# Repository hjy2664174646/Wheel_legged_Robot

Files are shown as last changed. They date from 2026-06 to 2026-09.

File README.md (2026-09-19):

# Wheel_legged_Robot

双轮足式平衡机器人项目，包含 RK3576 上位机 ROS 2 工作空间和 STM32 控制板下位机固件。系统通过串口桥接上位机与下位机，可完成机器人状态发布、底盘速度控制、SLAM 建图和 Nav2 自主导航。

## 项目结构

```text
Wheel_legged_Robot/
├── fishbot_ws/              # RK3576 上位机 ROS 2 工作空间
│   └── src/
│       ├── fishbot_bringup/       # 机器人启动、串口桥、TF/URDF 启动
│       ├── fishbot_description/   # 基础机器人描述
│       ├── fishbot_navigation2/   # slam_toolbox 与 Nav2 配置、地图、launch
│       ├── lslidar_driver/        # 雷神雷达 ROS 2 驱动
│       ├── lslidar_msgs/          # 雷达消息定义
│       ├── ros_serial2wifi/       # 串口/WiFi 辅助通信节点
│       ├── wheel_legged_urdf_pkg/ # 双轮足机器人 URDF、网格和 RViz 配置
│       └── ydlidar_ros2/          # YDLidar ROS 2 驱动
├── wheel_legged_ros/        # STM32 控制板下位机工程
│   ├── Core/                # STM32CubeMX 生成的 HAL/FreeRTOS 基础代码
│   ├── Drivers/             # STM32 HAL、CMSIS 等驱动
│   ├── Middlewares/         # FreeRTOS 中间件
│   ├── User/                # 平衡控制、腿部/轮部控制、IMU、CAN、电机和 ROS 通信
│   └── MDK-ARM/             # Keil MDK 工程文件
├── solidworks/              # 机械结构、加工图纸和三维模型
│   ├── hhu外壳改版sw/       # 外壳改版零件及 STL/3MF 导出文件
│   ├── 机加工图纸及模型/    # DXF 图纸、STEP 模型和加工 BOM
│   └── 机械结构.zip         # 机械结构资料压缩包
└── install.txt              # 依赖安装和设备规则记录
```

## 功能

- 双轮足式平衡机器人底盘控制
- STM32 下位机读取 IMU、轮端状态并执行平衡/运动控制
- 上下位机串口通信，默认设备名为 `/dev/serial_ttl`
- 上位机发布机器人 TF、URDF、里程计和雷达数据
- 支持 `slam_toolbox` 在线建图
- 支持 Navigation2 载入地图并进行自主导航
- 支持 RViz 可视化调试
- 提供机器人外壳、零件和机加工相关的 CAD 资料

## 硬件与软件环境

### 上位机

- RK3576
- Ubuntu 22.04
- ROS 2 Humble
- 雷达设备，默认可配置为 `/dev/lidar`
- 与 STM32 控制板连接的串口，默认可配置为 `/dev/serial_ttl`

### 下位机

- STM32H723 控制板
- FreeRTOS
- STM32 HAL
- Keil MDK-ARM / STM32CubeMX
- BMI088 IMU
- 达妙 DM4310 电机及 CAN 通信链路

## 机械设计资料

`solidworks/` 目录保存轮足机器人的机械结构资料，主要包括：

- `hhu外壳改版sw/`: 外壳改版零件的 SolidWorks `SLDPRT` 源文件，以及用于加工、打印或快速查看的 `STL`、`3MF` 文件
- `机加工图纸及模型/`: 机加工零件的 `DXF` 图纸、`STEP` 三维模型和 `BOM` 表格
- `机械结构.zip`: 机械结构资料的打包备份

SolidWorks 临时锁文件（文件名以 `~$` 开头）不会提交到仓库。修改或重新导出 CAD 文件后，请同步检查对应的 URDF 网格和装配尺寸，避免机械结构与仿真模型不一致。
## 上位机依赖安装

```bash
sudo apt update

sudo apt install -y \
  ros-humble-navigation2 \
  ros-humble-nav2-bringup \
  ros-humble-slam-toolbox \
  ros-humble-rviz2 \
  ros-humble-robot-state-publisher \
  ros-humble-joint-state-publisher \
  ros-humble-joint-state-publisher-gui \
  ros-humble-tf-transformations \
  ros-humble-pcl-conversions \
  ros-humble-diagnostic-updater \
  ros-humble-xacro \
  python3-colcon-common-extensions \
  python3-rosdep \
  python3-serial \
  libpcap-dev \
  libpcl-dev
```

如果 `rosdep` 尚未初始化：

```bash
sudo rosdep init
rosdep update
```

将当前用户加入串口权限组，执行后需要重新登录：

```bash
sudo usermod -a -G dialout $USER
```

## 设备规则

建议为 STM32 串口和雷达配置固定设备名，避免 `/dev/ttyACM*`、`/dev/ttyUSB*` 编号变化。

创建规则文件：

```bash
sudo nano /etc/udev/rules.d/99-wheel-legged-robot.rules
```

写入以下内容，并根据实际 `idVendor` / `idProduct` 调整：

```bash
# STM32 控制板串口 -> /dev/serial_ttl
SUBSYSTEM=="tty", ATTRS{idVendor}=="2e88", ATTRS{idProduct}=="4603", MODE="0666", SYMLINK+="serial_ttl"

# 雷达串口 -> /dev/lidar
SUBSYSTEM=="tty", ATTRS{idVendor}=="1a86", ATTRS{idProduct}=="7523", MODE="0666", SYMLINK+="lidar"
```

加载规则：

```bash
sudo udevadm control --reload-rules
sudo udevadm trigger
```

重新插拔设备后检查：

```bash
ls -l /dev/serial_ttl
ls -l /dev/lidar
```

## 编译上位机 ROS 2 工作空间

```bash
source /opt/ros/humble/setup.bash
cd ~/fishbot_ws
rosdep install --from-paths src --ignore-src -r -y
colcon build
source install/setup.bash
```

如果项目目录不是 `~/fishbot_ws`，请替换为实际路径。

## 启动机器人

启动底层 bringup，包括 URDF/TF、串口桥和雷达驱动：

```bash
source /opt/ros/humble/setup.bash
source ~/fishbot_ws/install/setup.bash
ros2 launch fishbot_bringup bringup.launch.py
```

`fishbot_bringup` 默认串口参数：

- `serial_port`: `/dev/serial_ttl`
- `baudrate`: `115200`

## 建图

先启动机器人 bringup，再在另一个终端启动 SLAM：

```bash
source /opt/ros/humble/setup.bash
source ~/fishbot_ws/install/setup.bash
ros2 launch fishbot_navigation2 slam_toolbox.launch.py use_sim_time:=false
```

建图完成后可使用 `slam_toolbox` 或 Nav2 相关工具保存地图到 `fishbot_ws/src/fishbot_navigation2/maps/`。

## 导航

启动机器人 bringup 后，在另一个终端启动 Nav2：

```bash
source /opt/ros/humble/setup.bash
source ~/fishbot_ws/install/setup.bash
ros2 launch fishbot_navigation2 navigation2.launch.py \
  map:=$HOME/fishbot_ws/src/fishbot_navigation2/maps/room.yaml \
  use_sim_time:=false \
  params_file:=$HOME/fishbot_ws/src/fishbot_navigation2/config/nav2_params.yaml
```

启动后可在 RViz 中设置初始位姿，并通过 `Nav2 Goal` 下发导航目标点。

## 下位机固件

`wheel_legged_ros/` 为 STM32 控制板代码，主要包含：

- `User/Controller`: 平衡与底盘控制逻辑
- `User/APP`: 左右腿/轮任务、状态观测、IMU、ROS 通信任务
- `User/Devices`: BMI088、DM4310 等设备驱动
- `User/Algorithm`: PID、Kalman、EKF、Mahony、VMC 等算法
- `User/Bsp`: CAN、PWM、DWT 等板级支持

编译和烧录步骤：

1. 使用 Keil MDK-ARM 打开 `wheel_legged_ros/MDK-ARM/CtrlBoard-H7_IMU.uvprojx`
2. 检查 STM32H723 目标芯片、调试器和下载配置
3. 编译工程并通过 ST-Link/J-Link 下载到控制板
4. 确认控制板串口连接到 RK3576，并与上位机串口桥保持 115200 波特率

## 上下位机通信

上位机通过 `fishbot_bringup/src/serial_bridge_node.py` 与下位机串口通信。下位机 `User/APP/ros_common.c` 中实现速度指令解析和里程计/IMU 数据发送。

- 上位机向下位机下发线速度 `vx` 与角速度 `wz`
- 下位机回传速度、角速度、位姿、IMU 和姿态数据
- 数据帧使用 `0xAA 0x55` 作为帧头，并带校验字段

## 注意事项

- 默认 bringup 使用 `lslidar_driver` 中的 `lsn10_launch.py`，请根据实际雷达型号调整 launch 或参数文件
- 如果串口设备名不是 `/dev/serial_ttl`，请修改 `fishbot_bringup/launch/bringup.launch.py`
- 导航前需要确认 TF、里程计、雷达 `/scan` 数据正常
- 真实机器人调试前请先确认急停、电池、电机方向和限位保护
- CAD 资料包含二进制和较大的 DXF 文件，首次克隆或拉取更新可能需要较长时间
- 当前仓库保存的是零件、导出模型和加工资料；如需完整 SolidWorks 装配体，请同时保留对应的 `SLDASM` 和引用零件文件

## 许可证

本项目当前未声明开源许可证。如需公开发布和二次分发，建议补充合适的 LICENSE 文件。

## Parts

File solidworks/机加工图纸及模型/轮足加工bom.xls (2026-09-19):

物料名称 | 材料 | 数量 | 单价
LIANGAN1 | 6061铝合金 | 2
LIANGAN3 | 6061铝合金 | 2
LIANGAN2 | 6061铝合金 | 2
LIANGAN4 | 6061铝合金 | 2
LVGUAN-1 | 6061铝合金方管 | 4
LVGUAN-2 | 6061铝合金方管 | 2
LVGUAN-3 | 6061铝合金方管 | 1
BANJIEJIAN-1 | 玻纤板-FR4 | 4
BANJIEJIAN-2 | 玻纤板-FR4 | 2
DIBAN-1 | 玻纤板-FR4 | 1
LIANJIEBAN-1 | 玻纤板-FR4 | 2
DINGBAN | 玻纤板-FR4 | 1
DINGGAI | 玻纤板-FR4 | 1

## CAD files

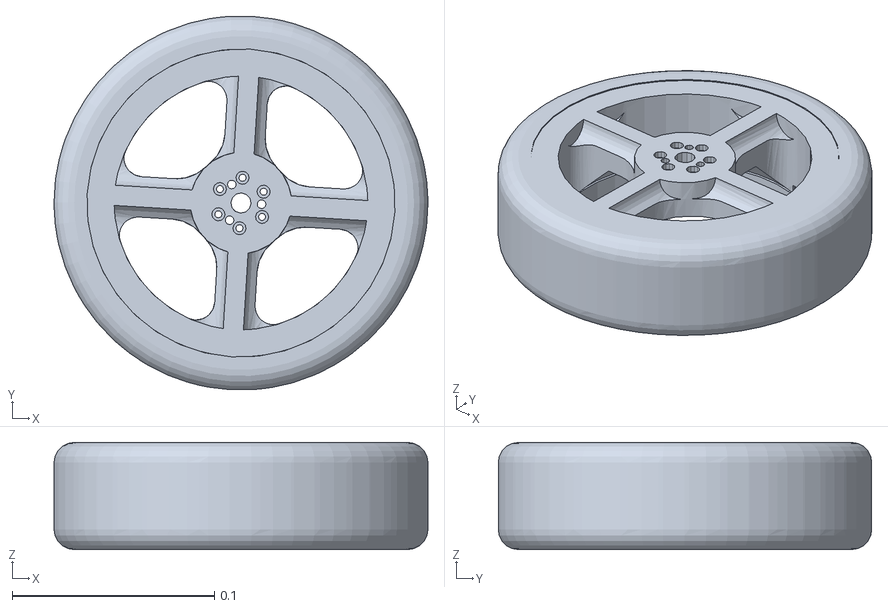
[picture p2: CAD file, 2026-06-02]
fishbot_ws/src/wheel_legged_urdf_pkg/meshes/right_wheel_motor_link.STL
0.185 x 0.185 x 0.053

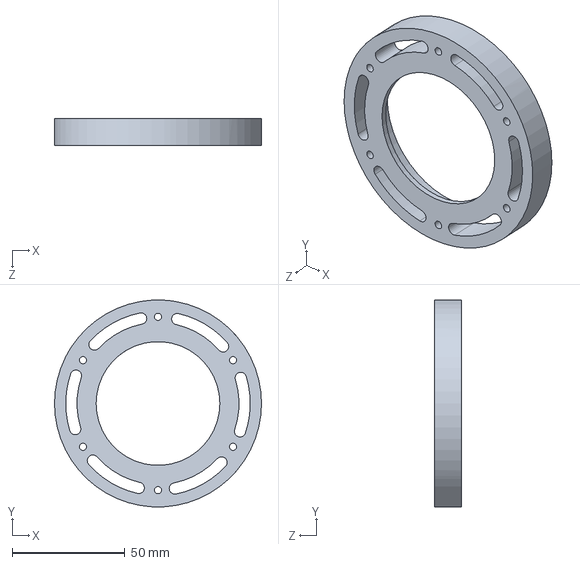
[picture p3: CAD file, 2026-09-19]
solidworks/hhu外壳改版sw/轮胎3.SLDPRT
92.0 x 91.8 x 12.0 mm

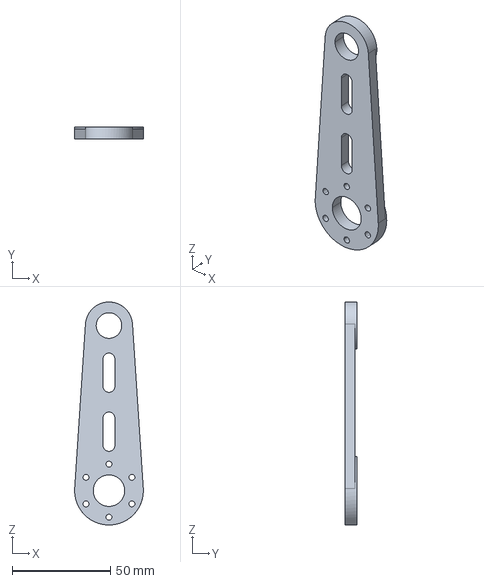
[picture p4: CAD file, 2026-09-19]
solidworks/机加工图纸及模型/liangan4.stp
35.0 x 6.00 x 113.5 mm

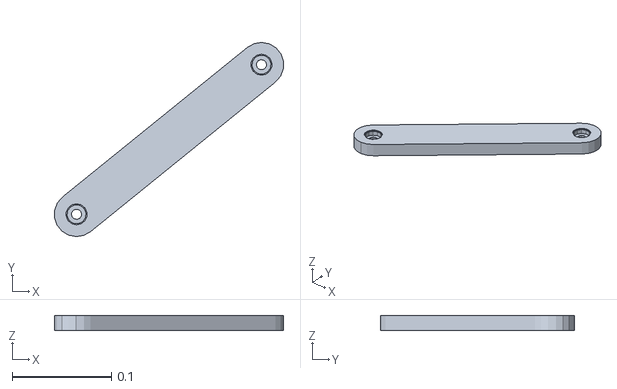
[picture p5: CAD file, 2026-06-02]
fishbot_ws/src/wheel_legged_urdf_pkg/meshes/right_l1_link.STL
0.231 x 0.196 x 0.015

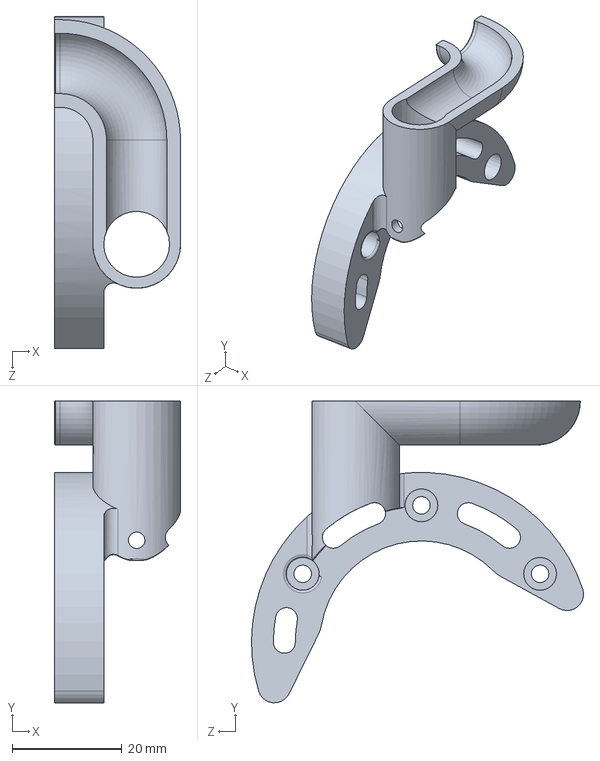
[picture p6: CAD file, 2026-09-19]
solidworks/hhu外壳改版sw/限位.SLDPRT
23.0 x 55.0 x 60.6 mm

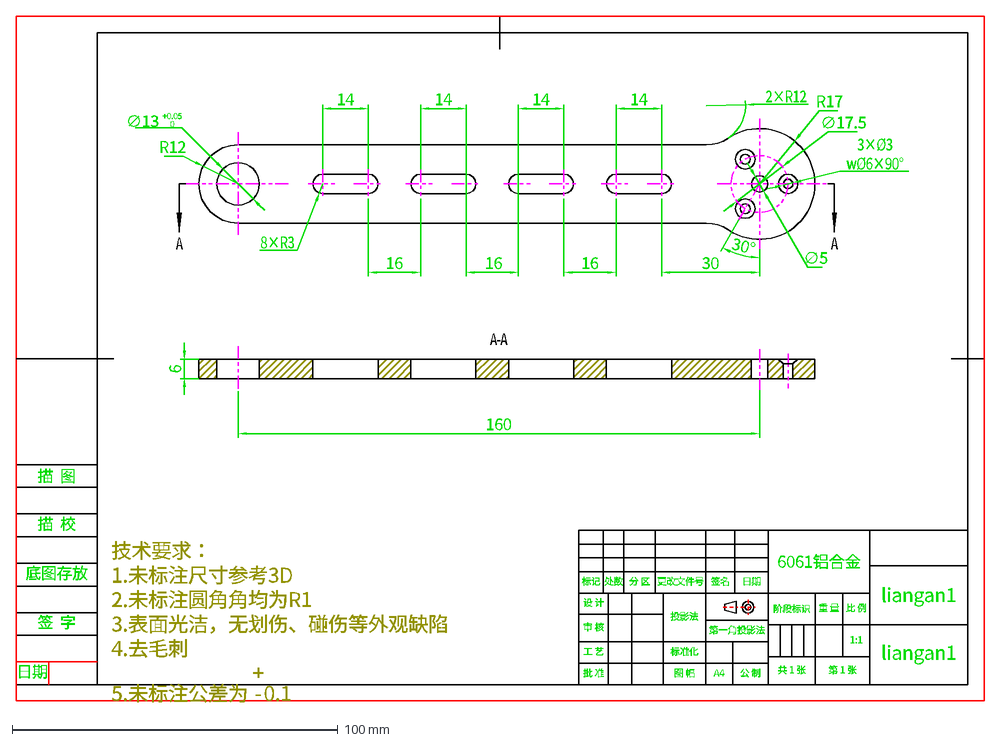
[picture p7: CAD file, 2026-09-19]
solidworks/机加工图纸及模型/liangna1.dxf
日期
签 字
底图存放
描 校
描 图
6061铝合金
liangan1
标记
处数
分 区
更改文件号
签名
设 计
投影法
阶段标识
重 量
比 例
审 核
第一角投影法
1:1
工 艺
标准化
共 1 张
第 1 张
批 准
图 幅
A4
公 制
技术要求： 1.未标注尺寸参考3D 2.未标注圆角角均为R1 3.表面光洁，无划伤、碰伤等外观缺陷 4.去毛刺 5.未标注公差为 +^-0.1
∅13 +0.05^0
R12
14
16
30
R17
6
160
30°
∅17.5
A-A
A
∅5

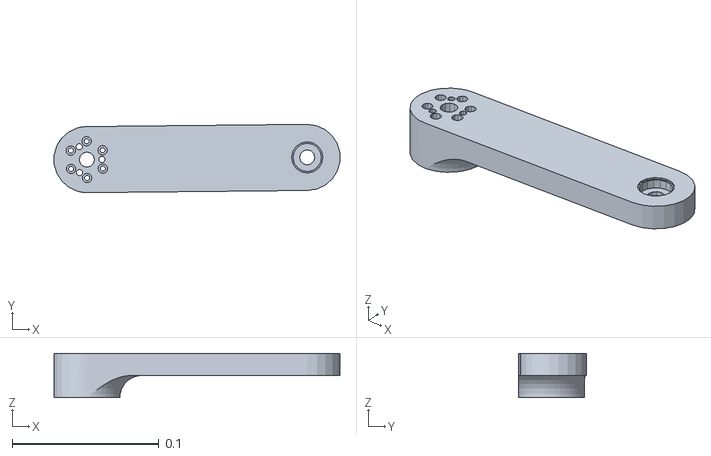
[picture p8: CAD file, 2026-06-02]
fishbot_ws/src/wheel_legged_urdf_pkg/meshes/left_front_motor_link.STL
0.195 x 0.0465 x 0.03

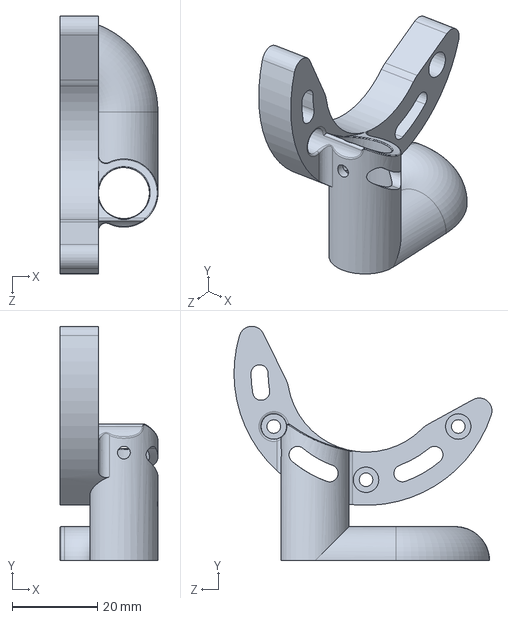
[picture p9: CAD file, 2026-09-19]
solidworks/hhu外壳改版sw/限位1.SLDPRT
23.0 x 55.0 x 60.6 mm

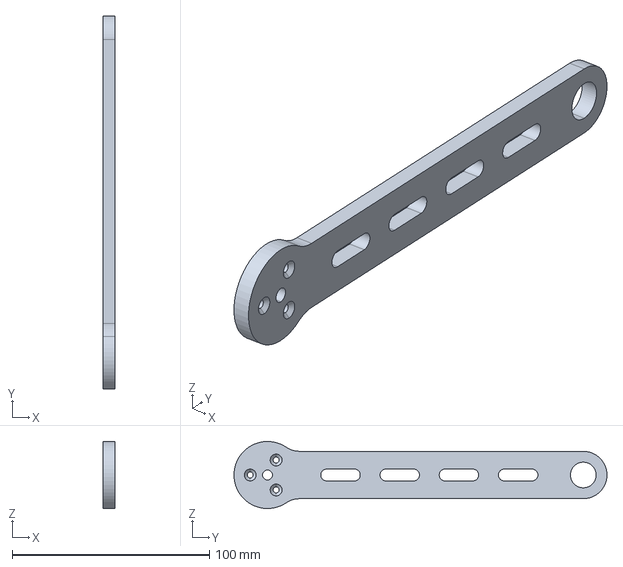
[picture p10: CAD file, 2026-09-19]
solidworks/机加工图纸及模型/liangan1.stp
6.00 x 189.0 x 34.0 mm

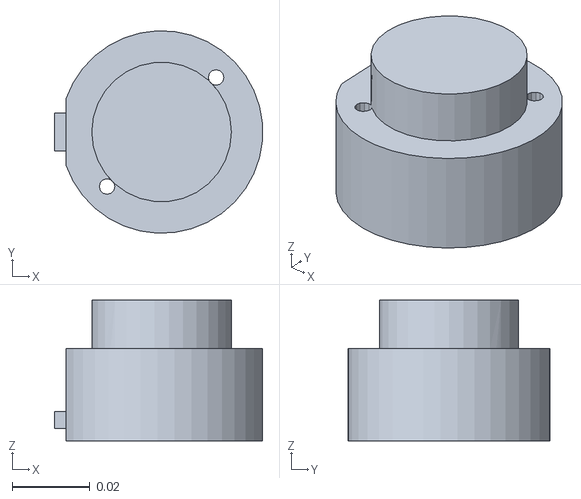
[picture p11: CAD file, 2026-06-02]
fishbot_ws/src/wheel_legged_urdf_pkg/meshes/lidar_link.STL
0.0534 x 0.052 x 0.0361

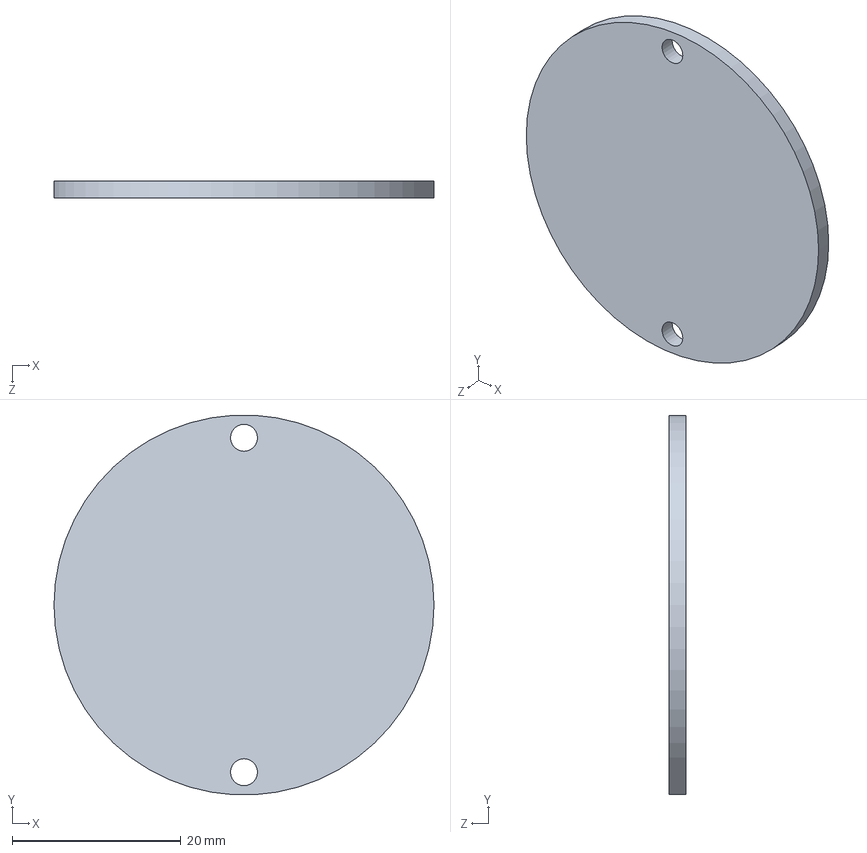
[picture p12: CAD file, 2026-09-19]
solidworks/hhu外壳改版sw/零件1.SLDPRT
45.0 x 44.9 x 2.00 mm

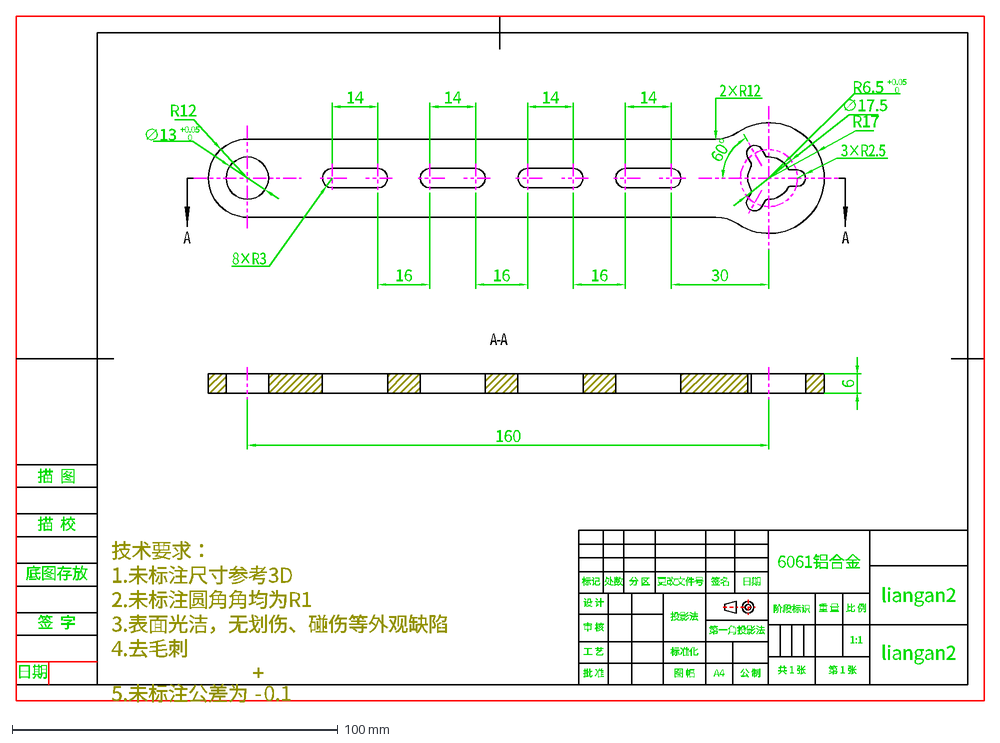
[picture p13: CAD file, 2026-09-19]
solidworks/机加工图纸及模型/liangna2.dxf
日期
签 字
底图存放
描 校
描 图
6061铝合金
liangan2
标记
处数
分 区
更改文件号
签名
设 计
投影法
阶段标识
重 量
比 例
审 核
第一角投影法
1:1
工 艺
标准化
共 1 张
第 1 张
批 准
图 幅
A4
公 制
技术要求： 1.未标注尺寸参考3D 2.未标注圆角角均为R1 3.表面光洁，无划伤、碰伤等外观缺陷 4.去毛刺 5.未标注公差为 +^-0.1
A-A
A
160
6
30
14
16
R12
R17
∅13 +0.05^0
∅17.5
R6.5 +0.05^0
60°

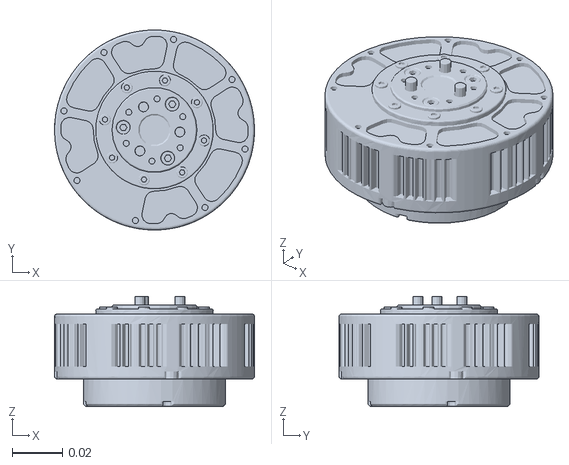
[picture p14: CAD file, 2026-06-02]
fishbot_ws/src/wheel_legged_urdf_pkg/meshes/right_l3_link.STL
0.08 x 0.08 x 0.044

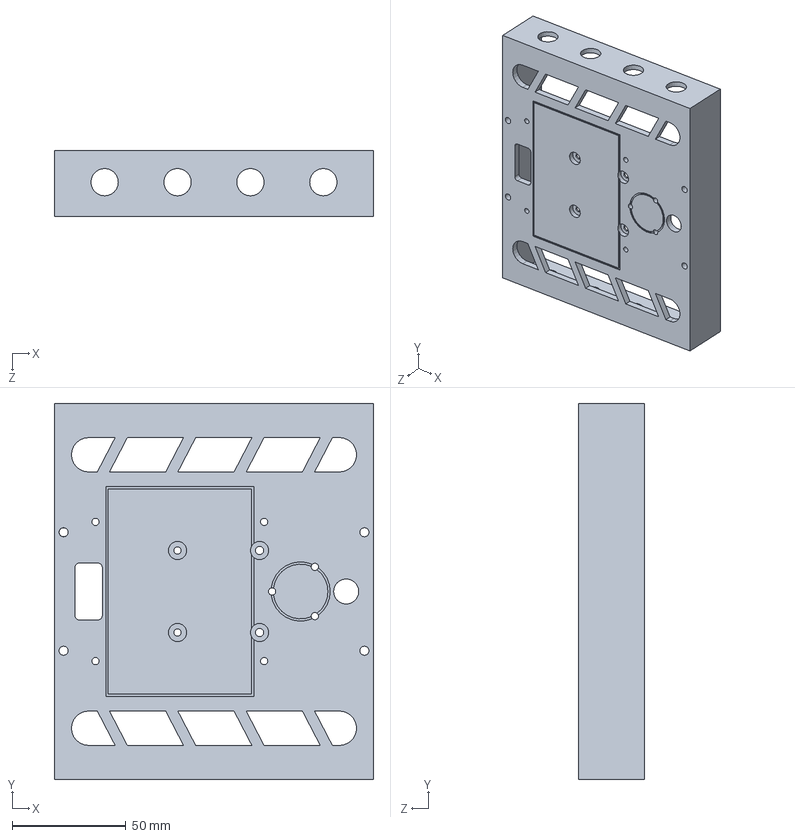
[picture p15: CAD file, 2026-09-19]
solidworks/hhu外壳改版sw/顶盖.SLDPRT
140.0 x 165.0 x 29.0 mm

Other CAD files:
solidworks/机加工图纸及模型/lvguan-3.stp
fishbot_ws/src/wheel_legged_urdf_pkg/meshes/right_front_motor_link.STL
solidworks/hhu外壳改版sw/电池仓.SLDPRT
solidworks/机加工图纸及模型/liangna3.dxf
fishbot_ws/src/wheel_legged_urdf_pkg/meshes/imu_link.STL
fishbot_ws/src/wheel_legged_urdf_pkg/meshes/left_back_motor_link.STL
fishbot_ws/src/wheel_legged_urdf_pkg/meshes/left_l1_link.STL
fishbot_ws/src/wheel_legged_urdf_pkg/meshes/left_l3_link.STL
fishbot_ws/src/wheel_legged_urdf_pkg/meshes/left_l4_link.STL
fishbot_ws/src/wheel_legged_urdf_pkg/meshes/left_wheel_motor_link.STL
fishbot_ws/src/wheel_legged_urdf_pkg/meshes/right_back_motor_link.STL
fishbot_ws/src/wheel_legged_urdf_pkg/meshes/right_l4_link.STL
solidworks/hhu外壳改版sw/N10雷达支架（抬高）.SLDPRT
solidworks/hhu外壳改版sw/前盖板（带开关充电口）.SLDPRT
solidworks/hhu外壳改版sw/前盖板（带开关充电口）.STL
solidworks/hhu外壳改版sw/摄像头支架.SLDPRT
solidworks/hhu外壳改版sw/限位.3mf
solidworks/hhu外壳改版sw/限位.STL
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

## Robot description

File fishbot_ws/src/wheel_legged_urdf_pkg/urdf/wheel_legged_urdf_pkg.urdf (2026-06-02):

<?xml version="1.0" encoding="utf-8"?>
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
<robot name="wheel_legged_urdf_pkg">
  <link name="base_link">
    <inertial>
      <origin xyz="0.00121782667412224 -0.000210352203166787 -2.21299226362964E-05" rpy="0 0 0" />
      <mass value="2.00185606218299" />
      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
    </inertial>
    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
  </link>
  <link name="left_front_motor_link">
    <inertial>
      <origin xyz="0.0624436684240075 0.000619326059130704 0.0200324549537225" rpy="0 0 0" />
      <mass value="0.141618184762676" />
      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
    </inertial>
    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
  </link>
  <joint name="left_front_joint_link" type="revolute">
    <origin xyz="0.042498 0.1395 0.00013155" rpy="-1.5708 -0.0033107 0" />
    <parent link="base_link" />
    <child link="left_front_motor_link" />
    <axis xyz="0 0 -1" />
    <limit lower="-3.14" upper="3.14" effort="111" velocity="111" />
  </joint>
  <link name="left_l1_link">
    <inertial>
      <origin xyz="-0.095105462450709 0.0731775307867209 -0.0163" rpy="0 0 0" />
      <mass value="0.177912779401" />
      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
    </inertial>
    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
  </link>
  <joint name="left_l1_joint_link" type="revolute">
    <origin xyz="0.14999 0.0015005 0.0238" rpy="0 0 0" />
    <parent link="left_front_motor_link" />
    <child link="left_l1_link" />
    <axis xyz="0 0 -1" />
    <limit lower="-3.14" upper="3.14" effort="111" velocity="111" />
  </joint>
  <link name="left_back_motor_link">
    <inertial>
      <origin xyz="-0.0749796058107964 0.0036928214728846 0.00747310925542913" rpy="0 0 0" />
      <mass value="0.115659747495916" />
      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
    </inertial>
    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
  </link>
  <joint name="left_back_joint_link" type="revolute">
    <origin xyz="-0.042501 0.1395 -0.00014986" rpy="-1.5708 -0.0033107 0" />
    <parent link="base_link" />
    <child link="left_back_motor_link" />
    <axis xyz="0 0 -1" />
    <limit lower="-3.14" upper="3.14" effort="111" velocity="111" />
  </joint>
  <link name="left_l4_link">
    <inertial>
      <origin xyz="0.128060879717462 0.0924384050013035 0.0178378642085842" rpy="0 0 0" />
      <mass value="0.248961638545411" />
      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
    </inertial>
    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
  </link>
  <joint name="left_l4_joint_link" type="revolute">
    <origin xyz="-0.14982 0.0073876 0.0062" rpy="0 0 0" />
    <parent link="left_back_motor_link" />
    <child link="left_l4_link" />
    <axis xyz="0 0 1" />
    <limit lower="-3.14" upper="3.14" effort="111" velocity="111" />
  </joint>
  <link name="left_l3_link">
    <inertial>
      <origin xyz="-0.000243308150557599 0.000117251658979897 0.0403173391634845" rpy="0 0 0" />
      <mass value="0.115219399015165" />
      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
    </inertial>
    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
  </link>
  <joint name="left_l3_joint_link" type="fixed">
    <origin xyz="0.1946 0.14047 0.0088" rpy="0 0 3.1416" />
    <parent link="left_l4_link" />
    <child link="left_l3_link" />
    <axis xyz="0 0 0" />
    <limit lower="-3.14" upper="3.14" effort="111" velocity="111" />
  </joint>
  <link name="left_wheel_motor_link">
    <inertial>
      <origin xyz="1.13167687540439E-07 1.25858476307528E-07 -0.00499719779399502" rpy="0 0 0" />
      <mass value="0.842051413621127" />
      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
    </inertial>
    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
  </link>
  <joint name="left_wheel_joint_link" type="continuous">
    <origin xyz="0 0 0.0565" rpy="0 0 3.1416" />
    <parent link="left_l3_link" />
    <child link="left_wheel_motor_link" />
    <axis xyz="0 0 -1" />
    <limit lower="0" upper="0" effort="111" velocity="111" />
  </joint>
  <link name="right_front_motor_link">
    <inertial>
      <origin xyz="0.0623057259191661 0.00415660632329509 0.0200324549608647" rpy="0 0 0" />
      <mass value="0.141618184759225" />
      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
    </inertial>
    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
  </link>
  <joint name="right_front_joint_link" type="revolute">
    <origin xyz="0.042501 -0.1395 0.00013156" rpy="1.5708 0 0" />
    <parent link="base_link" />
    <child link="right_front_motor_link" />
    <axis xyz="0 0 -1" />
    <limit lower="-3.14" upper="3.14" effort="111" velocity="111" />
  </joint>
  <link name="right_l1_link">
    <inertial>
      <origin xyz="-0.0932955290225116 -0.0754714798080031 -0.0162999999999999" rpy="0 0 0" />
      <mass value="0.177912779401" />
      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
    </inertial>
    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
  </link>
  <joint name="right_l1_joint_link" type="revolute">
    <origin xyz="0.14967 0.0099718 0.0238" rpy="0 0 0.0033107" />
    <parent link="right_front_motor_link" />
    <child link="right_l1_link" />
    <axis xyz="0 0 -1" />
    <limit lower="-3.14" upper="3.14" effort="111" velocity="111" />
  </joint>
  <link name="right_back_motor_link">
    <inertial>
      <origin xyz="-0.075017236320334 -0.00291294758678277 0.00747310925542902" rpy="0 0 0" />
      <mass value="0.115659747495916" />
      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
    </inertial>
    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
  </link>
  <joint name="right_back_joint_link" type="revolute">
    <origin xyz="-0.042498 -0.1395 -0.00014985" rpy="1.5708 -0.0033107 0" />
    <parent link="base_link" />
    <child link="right_back_motor_link" />
    <axis xyz="0 0 -1" />
    <limit lower="-3.14" upper="3.14" effort="111" velocity="111" />
  </joint>
  <link name="right_l4_link">
    <inertial>
      <origin xyz="0.130296403284804 -0.0892597043985118 0.0178378639085093" rpy="0 0 0" />
      <mass value="0.24896163452195" />
      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
    </inertial>
    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
  </link>
  <joint name="right_l4_joint_link" type="revolute">
    <origin xyz="-0.14989 -0.0058294 0.0062" rpy="0 0 0" />
    <parent link="right_back_motor_link" />
    <child link="right_l4_link" />
    <axis xyz="0 0 1" />
    <limit lower="-3.14" upper="3.14" effort="111" velocity="111" />
  </joint>
  <link name="right_l3_link">
    <inertial>
      <origin xyz="-2.80713764217733E-05 -0.000268623950909944 0.0403173391022381" rpy="0 0 0" />
      <mass value="0.115219399567085" />
      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
    </inertial>
    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
  </link>
  <joint name="right_l3_joint_link" type="fixed">
    <origin xyz="0.198 -0.13564 0.0088" rpy="0 0 0" />
    <parent link="right_l4_link" />
    <child link="right_l3_link" />
    <axis xyz="0 0 0" />
    <limit lower="-3.14" upper="3.14" effort="111" velocity="111" />
  </joint>
  <link name="right_wheel_motor_link">
    <inertial>
      <origin xyz="-6.16438811410977E-08 -1.57630152236576E-07 -0.00499719843039104" rpy="0 0 0" />
      <mass value="0.842051685465564" />
      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
    </inertial>
    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
  </link>
  <joint name="right_wheel_joint_link" type="continuous">
    <origin xyz="0 0 0.0565" rpy="0 0 0" />
    <parent link="right_l3_link" />
    <child link="right_wheel_motor_link" />
    <axis xyz="0 0 -1" />
    <limit lower="0" upper="0" effort="111" velocity="111" />
  </joint>
  <link name="imu_link">
    <inertial>
      <origin xyz="-0.00295011190315089 6.01878603506481E-05 -0.0022678069753778" rpy="0 0 0" />
      <mass value="0.0006342289369769" />
      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
    </inertial>
    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
  </link>
  <joint name="imu_joint_link" type="fixed">
    <origin xyz="0.0086888 0.0615 0.021391" rpy="0 -0.0033107 0" />
    <parent link="base_link" />
    <child link="imu_link" />
    <axis xyz="0 0 0" />
    <limit lower="-3.14" upper="3.14" effort="111" velocity="111" />
  </joint>
  <link name="laser">
    <inertial>
      <origin xyz="-0.000295667186511292 2.02745806254789E-17 -0.00821757116891281" rpy="0 0 0" />
      <mass value="0.0619661956356509" />
      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
    </inertial>
    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
  </link>
  <joint name="lidar_joint_link" type="fixed">
    <origin xyz="0.0450664766561181 -0.000722222222221321 0.103849771542335" rpy="0 -0.00331072414141279 0" />
    <parent link="base_link" />
    <child link="laser" />
    <axis xyz="0 0 0" />
    <limit lower="-3.14" upper="3.14" effort="111" velocity="111" />
  </joint>
</robot>

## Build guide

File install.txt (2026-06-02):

那就对路了，RK3576 + Ubuntu 22.04 + ROS 2 Humble 这套是能跑你这个工程的。

你现在要做的，基本就是把这个工程缺的依赖补齐。按你这个仓库来看，直接装下面这些就行。

先更新源：

sudo apt update
安装 ROS 相关包：

sudo apt install -y \
  ros-humble-navigation2 \
  ros-humble-nav2-bringup \
  ros-humble-slam-toolbox \
  ros-humble-rviz2 \
  ros-humble-robot-state-publisher \
  ros-humble-joint-state-publisher \
  ros-humble-joint-state-publisher-gui \
  ros-humble-tf-transformations \
  ros-humble-pcl-conversions \
  ros-humble-diagnostic-updater \
  ros-humble-xacro
安装 Python 和系统依赖：

sudo apt install -y \
  python3-colcon-common-extensions \
  python3-rosdep \
  python3-serial \
  libpcap-dev \
  libpcl-dev
如果 rosdep 还没初始化，再执行：

sudo rosdep init
rosdep update
然后给串口权限：

sudo usermod -a -G dialout $USER
执行完以后，注销重新登录 一次。

接着到你的工作空间里安装源码依赖并编译：

source /opt/ros/humble/setup.bash
cd ~/fishbot_ws
rosdep install --from-paths src --ignore-src -r -y
colcon build
source install/setup.bash
如果你的工作空间不是 ~/fishbot_ws，就换成你自己的目录。

再提醒你两个小点：

你这个工程默认启动的是 lslidar_driver，也就是雷神雷达，不是 YDLidar。要确认你的雷达型号对不对。
serial_bridge_node 默认串口是 /dev/serial_ttl，如果你机器上实际不是这个名字，后面 launch 时要改。
你可以先把上面这些装完。装完后如果愿意，我可以继续直接给你一份：

一、创建 udev 规则文件
bash
运行
sudo nano /etc/udev/rules.d/99-custom-serial.rules
把下面内容全部粘贴进去（已经用你提供的 idVendor/idProduct 写好了）：
bash
运行
# ttyACM0 → /dev/serial_ttl
SUBSYSTEM=="tty", ATTRS{idVendor}=="2e88", ATTRS{idProduct}=="4603", MODE="0666", SYMLINK+="serial_ttl"

# ttyUSB0 → /dev/lidar
SUBSYSTEM=="tty", ATTRS{idVendor}=="1a86", ATTRS{idProduct}=="7523", MODE="0666", SYMLINK+="lidar"
保存退出（Ctrl+O 回车，Ctrl+X）。
二、加载并生效规则
bash
运行
sudo udevadm control --reload-rules
sudo udevadm trigger
三、验证是否成功
拔掉再插一次两个设备，执行：
bash
运行
ls -l /dev/serial_ttl
ls -l /dev/lidar
如果输出类似这样，就成功了：
plaintext
lrwxrwxrwx 1 root root 7 May 20 10:00 /dev/serial_ttl -> ttyACM0
lrwxrwxrwx 1 root root 7 May 20 10:00 /dev/lidar -> ttyUSB0
四、后续使用方式
以后你的程序里，直接写固定设备名即可，再也不用管系统分配的编号了：
cpp
运行
// 原来的写法（可能变）
// "/dev/ttyACM0"
// "/dev/ttyUSB0"

// 现在的写法（永久固定）
"/dev/serial_ttl"
"/dev/lidar"

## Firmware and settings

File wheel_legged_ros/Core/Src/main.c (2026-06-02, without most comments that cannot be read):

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
/* Includes ------------------------------------------------------------------*/
#include "main.h"
#include "cmsis_os.h"
#include "dma.h"
#include "fdcan.h"
#include "spi.h"
#include "tim.h"
#include "usart.h"
#include "gpio.h"

/* USER CODE BEGIN Includes */
#include "BMI088driver.h"
#include "kalman_filter.h"
#include "mahony_filter.h"
#include "bsp_dwt.h"
#include "BMI088Middleware.h"
#include "can_bsp.h"
#include "ros_common.h"
/* USER CODE END Includes */


/* USER CODE BEGIN PV */
#define UART_RX_BUFFER_SIZE 200
uint8_t UART_RxBuffer[UART_RX_BUFFER_SIZE];

/* USER CODE END PV */

void SystemClock_Config(void);
void PeriphCommonClock_Config(void);
void MX_FREERTOS_Init(void);
/* USER CODE BEGIN 0 */
void HAL_UART_IDLECallback(UART_HandleTypeDef *huart)
{
    if(huart->Instance == USART1)
    {

        volatile uint32_t tmpreg;
        tmpreg = huart->Instance->ISR;
        tmpreg = huart->Instance->RDR;
        __HAL_UART_CLEAR_IDLEFLAG(huart);


        HAL_UART_DMAStop(huart);

        uint16_t recv_len = UART_RX_BUFFER_SIZE - __HAL_DMA_GET_COUNTER(huart->hdmarx);

        for(uint16_t i = 0; i < recv_len; i++)
        {
            ParseByte(UART_RxBuffer[i]);
        }


        HAL_UART_Receive_DMA(huart, UART_RxBuffer, UART_RX_BUFFER_SIZE);
    }
}



/* USER CODE END 0 */

/**
  * @brief  The application entry point.
  * @retval int
  */
int main(void)
{
  /* MCU Configuration--------------------------------------------------------*/

  /* Reset of all peripherals, Initializes the Flash interface and the Systick. */
      HAL_Init();

  /* USER CODE BEGIN Init */
//06 01 00 00 00 00 00 00 00 00 00 00 00 00 80 3F
  /* USER CODE END Init */

  /* Configure the system clock */
  SystemClock_Config();

/* Configure the peripherals common clocks */
  PeriphCommonClock_Config();

  /* Initialize all configured peripherals */
  MX_GPIO_Init();
  MX_DMA_Init();
  MX_SPI2_Init();
  MX_FDCAN1_Init();
  MX_FDCAN2_Init();
  MX_TIM3_Init();
  MX_FDCAN3_Init();
  MX_USART1_UART_Init();
  /* USER CODE BEGIN 2 */
	__HAL_UART_ENABLE_IT(&huart1, UART_IT_IDLE);
	DWT_Init(480);
  
    /* BMI088 */
  while (BMI088_init(&hspi2, 0) != BMI088_NO_ERROR)
	{
	  ;
	}
	Power_OUT1_ON;//imu
	Power_OUT2_ON;
	
  FDCAN1_Config();//can
	FDCAN2_Config();
	HAL_UART_Receive_DMA(&huart1, UART_RxBuffer, UART_RX_BUFFER_SIZE);
  /* USER CODE END 2 */

  /* Call init function for freertos objects (in freertos.c) */
  MX_FREERTOS_Init();

  /* Start scheduler */
  osKernelStart();

  /* We should never get here as control is now taken by the scheduler */
  /* Infinite loop */
  /* USER CODE BEGIN WHILE */
  while (1)
  {
    /* USER CODE END WHILE */

    /* USER CODE BEGIN 3 */
 
  }
  /* USER CODE END 3 */
}

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
/**
  * @brief  Period elapsed callback in non blocking mode
  * @note   This function is called  when TIM2 interrupt took place, inside
  * HAL_TIM_IRQHandler(). It makes a direct call to HAL_IncTick() to increment
  * a global variable "uwTick" used as application time base.
  * @param  htim : TIM handle
  * @retval None
  */
void HAL_TIM_PeriodElapsedCallback(TIM_HandleTypeDef *htim)
{
  if (htim->Instance == TIM2) {
    HAL_IncTick();
  }
}

/**
  * @brief  This function is executed in case of error occurrence.
  * @retval None
  */
void Error_Handler(void)
{
  /* USER CODE BEGIN Error_Handler_Debug */
  /* User can add his own implementation to report the HAL error return state */
  __disable_irq();
  while (1)
  {
  }
  /* USER CODE END Error_Handler_Debug */
}

#ifdef  USE_FULL_ASSERT
/**
  * @brief  Reports the name of the source file and the source line number
  *         where the assert_param error has occurred.
  * @param  file: pointer to the source file name
  * @param  line: assert_param error line source number
  * @retval None
  */
void assert_failed(uint8_t *file, uint32_t line)
{
  /* USER CODE BEGIN 6 */
  /* User can add his own implementation to report the file name and line number,
     ex: printf("Wrong parameters value: file %s on line %d\r\n", file, line) */
  /* USER CODE END 6 */
}
#endif /* USE_FULL_ASSERT */

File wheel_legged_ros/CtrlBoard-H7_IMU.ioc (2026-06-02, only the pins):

Mcu.UserName=STM32H723VGTx
PA0.GPIO_Label=DI
PA0.Signal=GPIO_Input
PA10.Signal=USART1_RX
PA13(JTMS/SWDIO).Signal=DEBUG_JTMS-SWDIO
PA14(JTCK/SWCLK).Signal=DEBUG_JTCK-SWCLK
PA2.GPIO_Label=DO
PA2.Signal=GPIO_Output
PA9.Signal=USART1_TX
PB1.Signal=S_TIM3_CH4
PB13.Signal=SPI2_SCK
PB5.Signal=FDCAN2_RX
PB6.Signal=FDCAN2_TX
PC0.GPIO_Label=ACC_CS
PC0.Signal=GPIO_Output
PC1.Signal=SPI2_MOSI
PC13.Signal=GPIO_Output
PC14-OSC32_IN.Signal=GPIO_Output
PC2_C.Signal=SPI2_MISO
PC3_C.GPIO_Label=GYRO_CS
PC3_C.Signal=GPIO_Output
PD0.Signal=FDCAN1_RX
PD1.Signal=FDCAN1_TX
PD12.Signal=FDCAN3_RX
PD13.Signal=FDCAN3_TX
PE10.GPIO_Label=ACC_INT
PE10.Signal=GPXTI10
PE12.GPIO_Label=GYRO_INT
PE12.Signal=GPXTI12
PE13.GPIO_Label=CLK
PE13.Signal=GPIO_Output
PE9.GPIO_Label=CS
PE9.Signal=GPIO_Output
PH0-OSC_IN.Signal=RCC_OSC_IN
PH1-OSC_OUT.Signal=RCC_OSC_OUT

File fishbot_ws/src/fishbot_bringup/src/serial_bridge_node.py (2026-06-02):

#!/usr/bin/env python3
import rclpy
import serial
import struct
from rclpy.node import Node
from geometry_msgs.msg import Twist
from geometry_msgs.msg import TransformStamped
from nav_msgs.msg import Odometry
from sensor_msgs.msg import Imu
#from transformations import quaternion_from_euler
from tf2_ros import TransformBroadcaster
from tf_transformations import quaternion_from_euler

class SerialBridgeNode(Node):
    def __init__(self):
        super().__init__('serial_bridge_node')

        # Allow port/baud configuration from launch files
        self.declare_parameter('serial_port', '/dev/serial_ttl')
        self.declare_parameter('baudrate', 115200)
        serial_port = self.get_parameter('serial_port').get_parameter_value().string_value
        baudrate = self.get_parameter('baudrate').get_parameter_value().integer_value

        self.vx = 0.0
        self.wz = 0.0
        
        # 创建订阅者
        self.cmd_sub = self.create_subscription(
            Twist,
            '/cmd_vel',
            self.cmd_vel_callback,
            10
        )
        
        # 初始化串口
        try:
            self.ser = serial.Serial(
                port=serial_port,
                baudrate=baudrate,
                timeout=0.01,
                parity=serial.PARITY_NONE,
                stopbits=serial.STOPBITS_ONE,
                bytesize=serial.EIGHTBITS,
                xonxoff=False,
                rtscts=False
            )
            self.get_logger().info(f'✅ Serial port {serial_port} opened successfully')
        except Exception as e:
            self.get_logger().error(f'❌ Failed to open serial port: {str(e)}')
            self.ser = None
        
        # 创建定时器（30Hz 发送）
        self.timer = self.create_timer(1.0 / 30, self.send_cmd_timer)
        
        # 数据接收 & 解析 & 发布
        self.odom_pub = self.create_publisher(Odometry, '/odom', 10)
        self.imu_pub = self.create_publisher(Imu, '/imu/data', 10)

        # 启动串口接收定时器
        self.create_timer(0.01, self.serial_read)

        # 用于帧解析
        self.rx_buffer = bytearray()
        
        self.get_logger().info('🚀 SerialBridgeNode started successfully')
        # 创建TF广播器
        self.tf_broadcaster = TransformBroadcaster(self)

    def serial_read(self):
        """从串口读取数据并解析 Odom 帧"""
        if not self.ser:
            return
            
        try:
            data = self.ser.read(60)
        except Exception as e:
            self.get_logger().error(f'Serial read error: {e}')
            return
            
        if not data:
            return

        self.rx_buffer.extend(data)

        # 找帧头：发送端是 0xAA55（uint16_t），小端存储→串口字节为 0x55 0xAA
        while len(self.rx_buffer) >= 60:
            # 正确判断帧头：读取前2字节（小端）是否等于 0xAA55
            if struct.unpack('<H', self.rx_buffer[:2])[0] != 0xAA55:
                self.rx_buffer.pop(0)
                continue

            # 帧总长度：60字节（与发送端结构体大小一致）
            if len(self.rx_buffer) < 60:
                return

            frame = self.rx_buffer[:60]
            
            # 先验证校验和
            checksum_recv = struct.unpack('<H', frame[58:60])[0]
            checksum_calc = sum(frame[2:58]) & 0xFFFF
            
            if checksum_calc != checksum_recv:
                self.get_logger().warn(f"❌ Checksum error: calc={checksum_calc}, recv={checksum_recv}")
                self.rx_buffer.pop(0)  # 只丢1字节，重新搜索帧头
                continue
            
            # 校验通过，移除这帧并解析
            self.rx_buffer = self.rx_buffer[60:]
            self.parse_odom_frame(frame)

    def parse_odom_frame(self, frame):
        """解析 60 字节的 Odom 帧（严格对齐发送端结构体）"""
        try:
            # 1. 验证帧头（二次确认，避免错位）
            head = struct.unpack('<H', frame[0:2])[0]
            if head != 0xAA55:
                self.get_logger().warn("❌ Frame header error")
                return

            # 2. 解析数据（严格按发送端结构体顺序）
            # 里程计核心数据：x→y→yaw→v→w
            x = struct.unpack('<f', frame[2:6])[0]        # 位置x (m)
            y = struct.unpack('<f', frame[6:10])[0]       # 位置y (m)
            yaw_odom = struct.unpack('<f', frame[10:14])[0]  # 里程计偏航角(rad)
            v = struct.unpack('<f', frame[14:18])[0]      # 线速度(m/s)
            w = struct.unpack('<f', frame[18:22])[0]      # 角速度(rad/s)
            
            # IMU 陀螺仪数据（3轴）
            gyro_x = struct.unpack('<f', frame[22:26])[0]  # Gyro[0]
            gyro_y = struct.unpack('<f', frame[26:30])[0]  # Gyro[1]
            gyro_z = struct.unpack('<f', frame[30:34])[0]  # Gyro[2]
            
            # IMU 加速度数据（3轴）
            accel_x = struct.unpack('<f', frame[34:38])[0] # Accel[0]
            accel_y = struct.unpack('<f', frame[38:42])[0] # Accel[1]
            accel_z = struct.unpack('<f', frame[42:46])[0] # Accel[2]
            
            # 姿态角：Pitch→Roll→Yaw（IMU偏航角）
            pitch = struct.unpack('<f', frame[46:50])[0]   # 俯仰角(rad)
            roll = struct.unpack('<f', frame[50:54])[0]    # 横滚角(rad)
            yaw_imu = struct.unpack('<f', frame[54:58])[0] # IMU偏航角(rad)
            
            # 校验和（uint16_t，小端）
            checksum_recv = struct.unpack('<H', frame[58:60])[0]

            # 3. 校验和计算（完全对齐发送端逻辑）
            # 发送端：sum(txBuffer[2:sizeof(odom)-2]) → 即 frame[2:58]（跳过2字节头+2字节校验和）
            checksum_calc = sum(frame[2:58]) & 0xFFFF  # 限制为16位（与发送端uint16_t匹配）

            # 4. 调试信息（精简输出，避免日志刷屏）
            self.get_logger().debug(f"Raw frame: {frame.hex()}")
            self.get_logger().info(
                f"📊 Odom: x={x:.3f} y={y:.3f} yaw={yaw_odom:.3f} v={v:.3f} w={w:.3f}"
            )
            #self.get_logger().info(
            #    f"📊 IMU: Gyro=[{gyro_x:.3f},{gyro_y:.3f},{gyro_z:.3f}] Accel=[{accel_x:.3f},{accel_y:.3f},{accel_z:.3f}]"
            #)
            #self.get_logger().info(
            #    f"📊 Attitude: Pitch={pitch:.3f} Roll={roll:.3f} Yaw={yaw_imu:.3f}"
            #)
            self.get_logger().info(f"🔍 Checksum: calc={checksum_calc} recv={checksum_recv}")

            # 校验和不匹配直接返回
            if checksum_calc != checksum_recv:
                self.get_logger().warn(f"❌ Checksum error: calc={checksum_calc}, recv={checksum_recv}")
                return

            # 5. 发布 Odometry 消息
            odom_msg = Odometry()
            odom_msg.header.stamp = self.get_clock().now().to_msg()
            odom_msg.header.frame_id = "odom"
            odom_msg.child_frame_id = "base_link"
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

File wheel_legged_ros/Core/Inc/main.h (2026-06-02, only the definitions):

#define ACC_CS_Pin GPIO_PIN_0
#define ACC_CS_GPIO_Port GPIOC
#define GYRO_CS_Pin GPIO_PIN_3
#define GYRO_CS_GPIO_Port GPIOC
#define DI_Pin GPIO_PIN_0
#define DI_GPIO_Port GPIOA
#define DO_Pin GPIO_PIN_2
#define DO_GPIO_Port GPIOA
#define CS_Pin GPIO_PIN_9
#define CS_GPIO_Port GPIOE
#define ACC_INT_Pin GPIO_PIN_10
#define ACC_INT_GPIO_Port GPIOE
#define GYRO_INT_Pin GPIO_PIN_12
#define GYRO_INT_GPIO_Port GPIOE
#define CLK_Pin GPIO_PIN_13
#define CLK_GPIO_Port GPIOE

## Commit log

2026-06-02 Initial commit for wheel-legged robot
    [fishbot.urdf, imu_link.STL, left_back_motor_link.STL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]
2026-09-19 Add SolidWorks models and manufacturing drawings
    [N10雷达支架（抬高）.SLDPRT, banjiejian-1.dxf, banjiejian-1.stp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]

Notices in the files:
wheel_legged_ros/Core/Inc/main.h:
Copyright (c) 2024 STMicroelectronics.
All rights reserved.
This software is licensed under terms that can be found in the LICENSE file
